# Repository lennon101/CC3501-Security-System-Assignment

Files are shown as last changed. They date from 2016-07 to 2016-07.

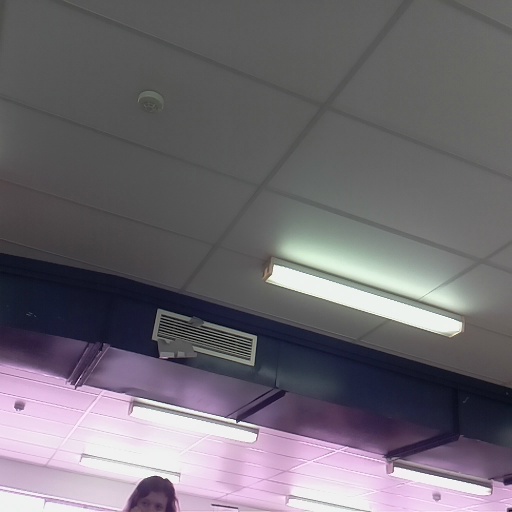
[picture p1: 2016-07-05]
SecuritySystem/src/images/1test.png

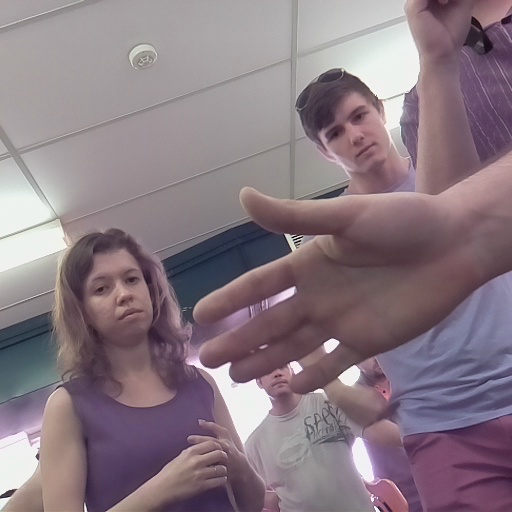
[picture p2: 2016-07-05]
SecuritySystem/src/images/5.png

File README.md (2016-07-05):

# CC3501-Security-System-Assignment

##ABSTRACT
The purpose of this project was to investigate, design and implement an indoor security system that involved wireless communication, motion detection, image processing as well as additional features including a website with a video stream and control features. The projects objective has been to innovate an easy to use and affordable system ready for consumer use. This technical report provides and overview of the investigation, design and implementation done to deploy the project prototype.

##CC3501
- GROUP 5: Dane Lennon, Michael Grasso, Stuart Hinchliff, Stephanie Baker

##Project Features and Functionality
This system involves the integration of both hardware and software. It features a custom microprocessor PCB with a PIR motion detecting sensor communicating with a Raspberry Pi via XBee communications.
The features of this project include:
- Webserver application interface with full functionality
- The ability to arm and disarm the system
- Low power initial motion detection using a PIR sensor
- A second check for motion detection with complex image detection algorithms
- Voice configuration mode 
- Ability to email and save screenshots

##Hardware Design
###Printed Circuit Board Design
When designing this system, it was a priority that it must be as small and efficient as possible and only include the minimum number of necessary hardware features on the PCB, these included:
- PIR sensor for motion detection,
- LED to indicate motion detection 
- USB 2.0 port for power and necessary power supply regulations 
- Xbee for Zigbee communication
- JTAG header for SEGA programming 
- Battery holder for backup power

To reduce the size of this board further, a custom microprocessor board was designed to replace the standard shield for a Freescale Board. The Freescale FRDM-K20D50M schematic was used as a reference through the design process. Therefore, the microprocessor design, including the clock source and decoupling capacitor designs, was executed similarly to a professional board design. Figure 3 shows the completed PCB. 

###Central Hub and Peripherals
Implementing a security system with advanced features such as image processing and voice control was a task that could only be performed using a highly functional and heavily customizable device. The obvious choice was a Raspberry Pi, with capabilities of a small computer running the Linux operating system. The Raspberry Pi offers all of the features required by the group to design the central hub. Additionally, many open-source libraries are available for Linux to assist with the necessary features of the system such as the development of image processing, voice control and video streaming.

The Raspberry Pi B+ model features two USB ports and a 3.5mm audio jack, allowing the group to attach all required devices with ease. Additionally, a ribbon camera designed specifically for the Raspberry Pi is available, allowed for easy connection of a camera. The list of peripherals used in this project are:
Raspberry Pi Camera Board 
- USB 2.0 Microphone 
- Wi-Pi USB 2.0 Connector
- Powered USB 2.0 Hub

##Software Design
Robust was fundamental to the project. The system integrates scripts in C, C++, Python, HTML, JavaScript, and many external frameworks and libraries. The two main scripts were the C++ code running the main hub, and the Python code operating the webserver. Details of the functionality are described below.

###Server and Web-application
In order to appropriately develop the project, the target audience and their needs were carefully considered. It was assumed that average users would have no prior technical experience with embedded systems, so the software was designed to be user friendly.
A number of control methods were contemplated in the design process, including the use of a Bluetooth or web application. Upon review of similar products available it was determined that a web application provided the flexibility desired with: 
- Range of use (only an internet connection required 
- Security (authentication methods)
- Interface (intuitive GUI)
- Accessibility on a range of devices
- Potential for expansion
 
Various frameworks were considered to host the server. Due to its popularity and power, the lightweight, Python-based, framework called Flask was chosen. Further, a Bootstrap template was used for the webpage structure to improve the visual appeal and enhance user experience.

####Video Streaming
Surveillance is becoming increasingly prevalent in security systems and was the main drive for developing a web application. The implementation of this was inspired by Miguel Grinberg’s live video stream [1], which demonstrated how versatile Flask could be.
The main complication with using Python was its compatibility with the existing C++ code. It was found that a conflict occurred when attempting to access the camera from Python (for video streaming) and C++ (for image processing) scripts simultaneously. To overcome this, it was decided that saving an image from the C++ code and loading it to Python was the most feasible option. This came with a variety of advantages and disadvantages. It reduced the complexity of the code and it also provided a saved image for use in other processes, but the continuous read/write of images does consume system time. Sockets were also considered, but for image matrices proved complicated and prone to problem.

####Web-Application Control
The website comprises of three main pages: dashboard, view screenshots, and email configuration. The functionality of the website is as follows: (see Figure 2 for flowchart):
- Dashboard: View the live stream and execute available commands.
- Arm (Default): Receive data from the PCB. If a 1 (motion detected) is received image processing code is executed and an email is sent to the saved address.
- Disarm: Stop receiving data from the PCB.
- Save a SnapShot: Capture image of the live stream.
- Email a SnapShot: Send an email of the current image to the saved address.
- Enable Voice: Turn on voice control, allowing the user to configure via voice. o Disable Voice (Default): Turn off voice control.

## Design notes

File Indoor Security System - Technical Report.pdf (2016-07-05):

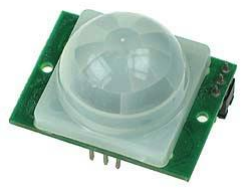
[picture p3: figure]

## Technical Report

### ABSTRACT

The purpose of this project was to investigate, design and implement an indoor security system that involved wireless communication, motion detection, image processing as well as additional features including a website with a video stream and control features. The projects objective has been to innovate an easy to use and affordable system ready for consumer use. This technical report provides and overview of the investigation, design and implementation done to deploy the project prototype.

GROUP 5: Dane Lennon, Michael Grasso,

### Stuart Hinchliff, Stephanie Baker

CC3501

## Contents

# 1. Project Overview

### 1.1 Project Approach

The investigative approach of the Indoor Security System Project began with researching systems currently on the market and analysing their specifications. It was found that most existing systems integrate motion detection algorithms with a continuously running camera to detect motion. One of the design criteria of this project was to utilise a low-power sensor network to implement motion detection over a large area with minimal cost. Therefore, using the camera continuously for motion detection was not suitable.

To minimize the use of the camera, a Photoelectric (“Passive”) Infrared Sensor was implemented. It was chosen for several reasons, including its ability to detect changes in infrared radiation as well as its low cost and low power consumption. If there is a differential change within the scope of the sensor, the sensors convert it into an output voltage, which represents a detection, illustrated in Figure 1.

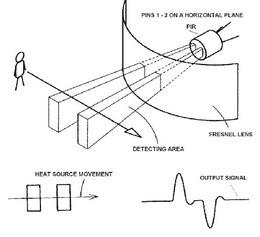
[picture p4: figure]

### 1.2 Project Features and Functionality

This system involves the integration of both hardware and software. It features a custom microprocessor PCB with a PIR motion detecting sensor communicating with a Raspberry Pi via XBee communications.

The features of this project include:
- Webserver application interface with full functionality
- The ability to arm and disarm the system
- Low power initial motion detection using a PIR sensor
- A second check for motion detection with complex image detection algorithms
- Voice configuration mode
- Ability to email and save screenshots

Included in Figure 2 is a flow chart illustrating how the system works when being controlled by the user.

Figure 1: PIR SENSOR [2]

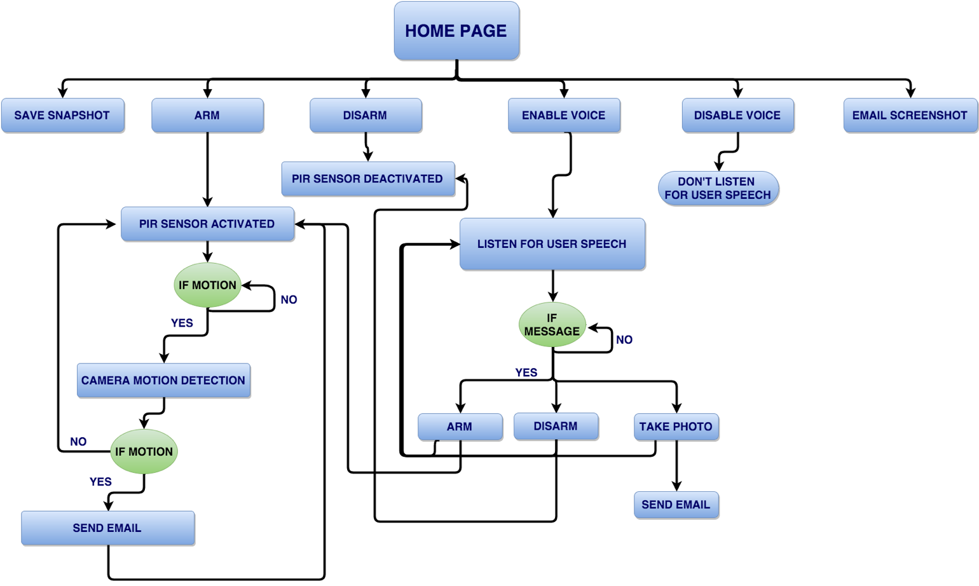
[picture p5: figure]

## 2. Hardware Design

### 2.1 Printed Circuit Board Design

When designing this system, it was a priority that it must be as small and efficient as possible and only include the minimum number of necessary hardware features on the PCB, these included:

- PIR sensor for motion detection,
- LED to indicate motion detection
- USB 2.0 port for power and necessary power supply regulations
- Xbee for Zigbee communication
- JTAG header for SEGA programming
- Battery holder for backup power

To reduce the size of this board further, a custom microprocessor board was designed to replace the standard shield for a Freescale Board. The Freescale FRDM-K20D50M schematic was used as a reference through the design process. Therefore, the microprocessor design, including the clock source and decoupling capacitor designs, was executed similarly to a professional board design. Figure 3 shows the completed PCB.

Figure 2: Flow Chart- System Design

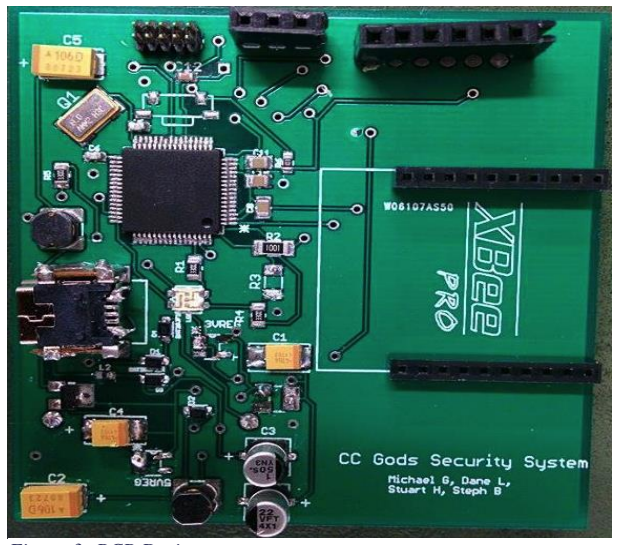
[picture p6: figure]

### 2.2 Communications Network

The wireless communications network utilised in this system is a ZigBee mesh network. The ZigBee network used consists of one Coordinator connected to the Raspberry Pi and one Router connected to PCB. This was designed so multiple PCBs can be distributed, automatically forming a mesh network with the Coordinator at the central hub. Figure 4 illustrates the ZigBee communication network outlined above.

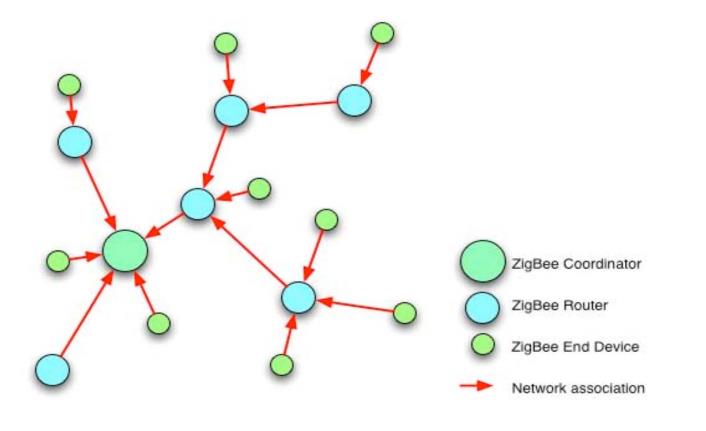
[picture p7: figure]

### 2.3 Central Hub and Peripherals

Implementing a security system with advanced features such as image processing and voice control was a task that could only be performed using a highly functional and heavily customizable device. The obvious choice was a Raspberry Pi, with capabilities of a small computer running the Linux operating system. The Raspberry Pi offers all of the features required by the group to design the central hub. Additionally, many open-source libraries are available for Linux to assist with the necessary features of the system such as the development of image processing, voice control and video streaming.

The Raspberry Pi B+ model features two USB ports and a 3.5mm audio jack, allowing the group to attach all required devices with ease. Additionally, a ribbon camera designed specifically for the Raspberry Pi is available, allowed for easy connection of a camera. The list of peripherals used in this project are:

- Raspberry Pi Camera Board

Figure 3: PCB Design

Figure 4: ZigBee Network [5]

- USB 2.0 Microphone
- Wi-Pi USB 2.0 Connector
- Powered USB 2.0 Hub

These peripherals were connected to the powered USB 2.0 hub to ensure devices would receive enough power and not switch off.

## 3.0 Software Design

Robust was fundamental to the project. The system integrates scripts in C, C++, Python, HTML, JavaScript, and many external frameworks and libraries. The two main scripts were the C++ code running the main hub, and the Python code operating the webserver. Details of the functionality are described below.

### 3.1 Main Loop

The main loop controls the system and is responsible for automation of the security system. The structure of the code is demonstrated Figure 5.

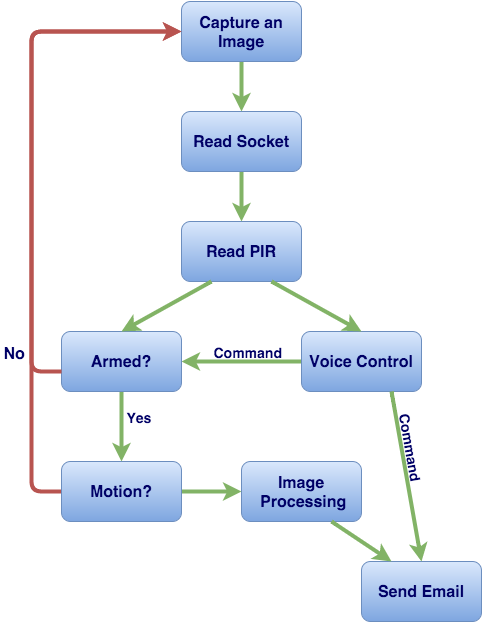
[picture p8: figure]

### 3.2 Server and Web-application

In order to appropriately develop the project, the target audience and their needs were carefully considered. It was assumed that average users would have no prior technical experience with embedded systems, so the software was designed to be user friendly.

A number of control methods were contemplated in the design process, including the use of a Bluetooth or web application. Upon review of similar products available it was determined that a web application provided the flexibility desired with:

- Range of use (only an internet connection required)
- Security (authentication methods)
- Interface (intuitive GUI)
- Accessibility on a range of devices
- Potential for expansion

Figure 5: Main Loop Logic

Various frameworks were considered to host the server. Due to its popularity and power, the lightweight, Python-based, framework called Flask was chosen. Further, a Bootstrap template was used for the webpage structure to improve the visual appeal and enhance user experience.

3.2.1. Video Streaming
Surveillance is becoming increasingly prevalent in security systems and was the main drive for developing a web application. The implementation of this was inspired by Miguel Grinberg’s live video stream [1], which demonstrated how versatile Flask could be.

The main complication with using Python was its compatibility with the existing C++ code. It was found that a conflict occurred when attempting to access the camera from Python (for video streaming) and C++ (for image processing) scripts simultaneously. To overcome this, it was decided that saving an image from the C++ code and loading it to Python was the most feasible option. This came with a variety of advantages and disadvantages. It reduced the complexity of the code and it also provided a saved image for use in other processes, but the continuous read/write of images does consume system time. Sockets were also considered, but for image matrices proved complicated and prone to problem.

3.2.2 Web-Application Control
The website comprises of three main pages: dashboard, view screenshots, and email configuration. The functionality of the website is as follows: (see Figure 2 for flowchart):
- Dashboard: View the live stream and execute available commands.
- Arm (Default): Receive data from the PCB. If a 1 (motion detected) is received image processing code is executed and an email is sent to the saved address.
- Disarm: Stop receiving data from the PCB.
- Save a SnapShot: Capture image of the live stream.
- Email a SnapShot: Send an email of the current image to the saved address.
- Enable Voice: Turn on voice control, allowing the user to configure via voice.
- Disable Voice (Default): Turn off voice control.

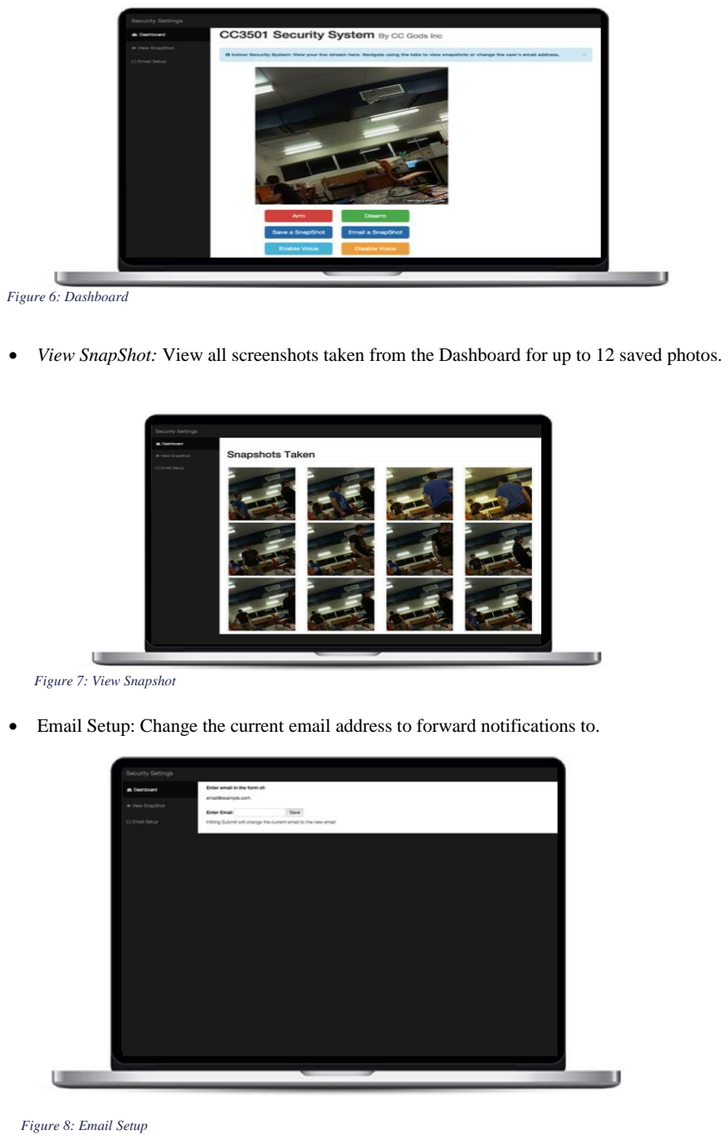
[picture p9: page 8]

- View SnapShot: View all screenshots taken from the Dashboard for up to 12 saved photos.
- Email Setup: Change the current email address to forward notifications to.

Figure 6: Dashboard

Figure 7: View Snapshot

Figure 8: Email Setup

3.2.3 Integration
Multilingual programming was an important aspect of the overall project. In order to ensure various scripts cooperated together, careful consideration of individual tasks and the overall product was taken in design.

The ability to email from the application was a significant feature, with details on its implementation available in Section 3.5. The Python script containing the code is called using a system call from either the C++ or Python code. Due to the sequential nature of the languages used, this caused a halt in the program preventing streaming, voice control and most importantly motion detection. To overcome this, forks were implemented.

Forks are a system call used in Unix-based systems in which a process creates a copy of itself. This process is best explained through the use of a flowchart:

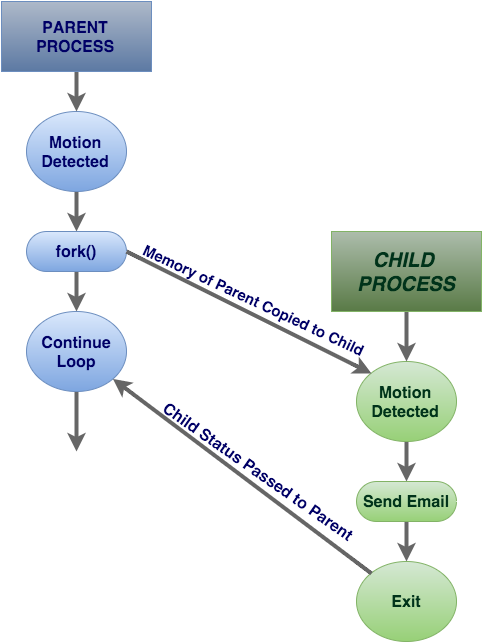
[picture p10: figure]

The C++ script creates a fork when motion is detected, prior to calling the email function. The parent continues looking for motion while the child process simultaneously executes the email script and is then destroyed.

Acquiring information from the website and sharing it between processes was a crucial part of controlling the system. Flask handled routes from the HTML script, so button clicks were accessible from Python. Non-blocking UDP/IP sockets were then used to transfer the information to the C++ code. UDP/IP was chosen as only two Boolean numbers needed to be sent, and the lack of error checking and overhead increased speed. Additionally, as the sockets were operating on the same system, there would be no loss of data and no need for retransmission.

### 3.3 Voice Control

The concept of voice control is a very marketable design and could potentially be implemented a variety of ways into any system in order to create an easy-to-use interface for the consumer. It was introduced to this security system as a prototype level feature. In future, it could be expanded to have more complete control.

Figure 9: Flow Chart- Fork

3.3.1 Speech-To-Text Input

There are several speech-to-text engines available for the Raspberry Pi. The two engines considered were Pocketsphinx and Julius, both well known for their voice recognition capabilities. After research on these two speech engines it was determined that Pocketsphinx was the engine best suited to a project with small sentence structures. It is designed for small systems and implements natural language processing, including advanced algorithms such as n-grams and Hidden Markov Models. A logic diagram for Pocketsphinx can be seen in Figure 10.

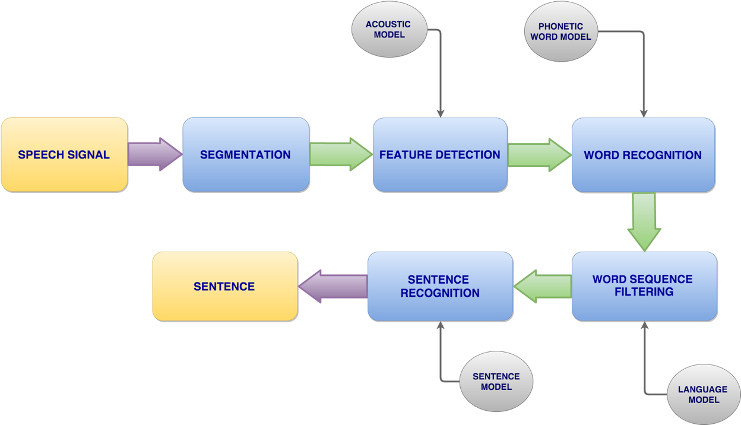
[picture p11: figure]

This speech engine required extensive configuration and modification to suit our purposes. Word recognition was improved using a grammar model tool by Carnegie Mellon University, which involved creating a .txt file containing required commands. The tool generated language and dictation models which were implemented in the C++ code. The dictation model file was then manually modified to include pronunciations consistent with the Australian accent, as initially it contained only American pronunciations.

3.3.2. Text-to-Speech Output
In order to complete a full speech structure, speech synthesis allows the system to talk back to the user. After researching several speech synthesis engines, eSpeak was implemented due to its usability. It was implemented in the C++ code through a system call to pass a string to command line which would generate the desired speech response. Text-to-speech output was used to interact with the user while voice control configuration was active.

### 3.4. Image Processing for Motion Detection

3.4.1. Image Processing Techniques
There are a number of ways to approach detecting motion using a camera. After extensive research the method which was utilised in this algorithm was the comparison of three frames captured after slight time delay in order optimise the reduction of would background noise. The images are stored as 512 x 512 pixel matrices and processed in C++ with the implementation of OpenCV libraries. The absdiff() function was used twice to take the element-by-element absolute difference between two matrices and return a resultant matrix. Example output of absdiff() is seen in Figure 11.

Figure 10: Flow Chart- Pocketsphinx

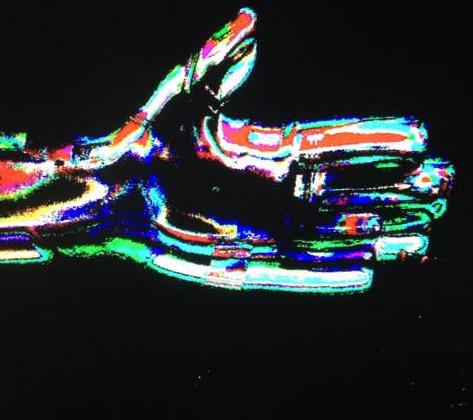
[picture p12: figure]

Figure 11 - Image of moving hand after absdiff() is applied

Figure 11 shows that there are some undesired image artefacts, such as the cluster of white pixels in the bottom right corner. In the application of motion detection, it is undesirable to have this background noise in difference images as it triggers a false positive for movement.

To remove artifacts in images, the frames were compared using an OpenCV function bitwise_and(), which takes two image matrices as input and performs a logical ‘and’ operation on each pixel, resulting in a significant reduction of background artifacts. Thisfunction produces a resultant matrix where pixels which are the same colour in image 1and image 2 are returned unchanged, while all other pixels are converted to black.

After artefact removal, the image is converted to greyscale and binary thresholding is performed to eliminate remaining background noise while preserving the foreground image. Binary thresholding returned an image whereby white pixels represent pixels that changed colour between frames, while black pixels are those that remained the same colour.

It was determined through manual testing that if the white pixel count was over 20 pixels, motion had occurred. A bounding rectangle was drawn around the movement region by generating a rectangle between minimum and maximum (x, y) coordinates of the detected movement and overlaying it on captured frames. This makes it easier to pinpoint the source of movement.

### 3.5 Emailing System

The security system has been implemented with an emailing system with two methods of activation. Emailing of images can be triggered manually from the webpage, or automatically by the C++ code if motion is detected.

3.5.1 Manually Capture and Email a Snapshot
The email system was written in Python, using StackOverflow as a guide. The script is run from the command line and contains information about the location of the images to attach and the addresses of sender and receiver. The website dashboard includes a button to manually email a snapshot. The onClick listener of the button calls a function attached to an xhttp route which executes the Python script on the server side.

3.5.2 Automatic Email Alert
When motion is detected by the C++ code, a fork is created and the child process sends an email via a system call to the Python Script.

## 4.0 Limitations and Recommendations

### 4.1 Hardware

4.1.1 Component Limitations
The design of the Printed Circuit Board (PCB) was derived from the Freescale Freedom schematic and similar components chosen to match the design. However, during implementation, some components intermittently failed. This included an unresolved voltage output error from the buck boost regulator, which returned approximately 3.7V instead of the expected 5V. The system was redesigned using a though-hole 3.3V linear regulator to overcome this, but the required component could not be purchased before project completion due to time constraints. Further, the use of the linear regulator would have resolved the first issue but in turn produced a second issue where the battery could not have been used.

4.1.2 Design Flaws
During the design stage, flaws occurred in the PCB schematic layout when the USB footprint was placed backwards on the Eagle board layout.

This design flaw was overcome by soldering the USB facedown and wiring the pins of the USB to the tracks of the PCB as shown below. A copper sheet was used to ensure the USB did not make any undesired electrical connections with other PCB tracks. This worked well as a fix, but in the future the design could be easily corrected.

Lastly, the design made use of a surface mounted microprocessor. After the components were placed on the board, it became evident that too much solder paste had been used around the terminals of the processor, as shown below. This resulted in time-consuming re-soldering before the PCB was at a satisfactory level.

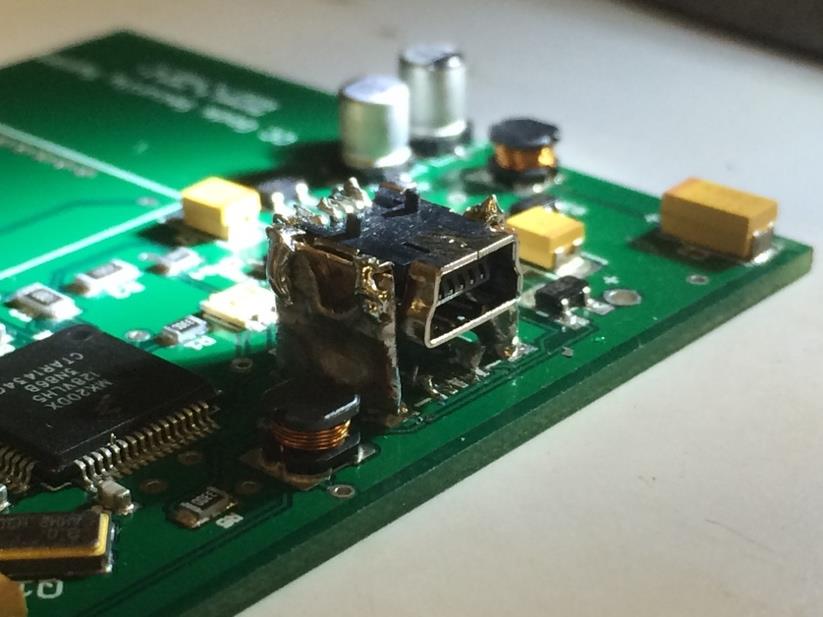
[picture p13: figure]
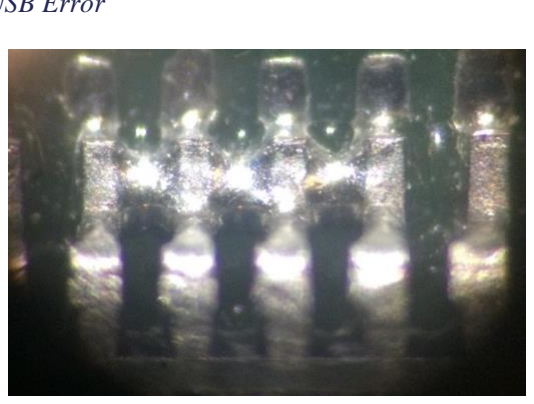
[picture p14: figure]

Figure 12: USB Error

4.1.3 Future Design Implementations
The initial scope of the project included a custom made 3D printed case to house the PCB. However, due to the time constraints of the project the implementation of this feature was discarded in order to prioritized the technical design. Future designs would also resolve the issues outlined above, and off-the-shelf installation and implementation would be implemented for increased usability.

### 4.2 Software

4.2.1 Voice Control
The implementation of voice control was limited by the recognition engine and microphone quality. Background noise needed to be removed for full accuracy, and the engine did not process all voices with equal effectiveness. While this is a software limitation, it could be overcome by improving the engine to accept a wider variety of voice pitches, dialects and accents. However, this was outside the reasonable scope of a time-constrained project. Voice control also needed to be listening at all times to recognize words, which became problematic when the C++ code also needed to listen to a socket and the XBee.

4.2.3 Saving images
Currently, the system has been designed to save the images to the Pi and load the images to the webpage. This is not an ideal implementation and could be improved using sockets. This would involve sending the data from the C++ code to the Python code in matrix format via UDP/IP. The client side (Python) would receive the matrix and format the image for webpage display.

4.2.4 Image Detection
The image detection algorithm was optimized for an indoor environment, where movement is minimal and lighting is consistent. For an outdoor environment with a dynamic background, new algorithms would need to be developed to accurately detect only relevant movement.

## 5.0 Conclusion

The scope of the project included the design and implementation of a security system that made use of wireless communication between microcontrollers, motion detection and multiple methods of control such a web app and voice control. These design requirements were successfully implemented with only a few limitations. While most limitations were due to uncontrollable parameters, some flaws were introduced that could have been avoided and these have been documented for future designs. The final product provides a suitable working prototype of an affordable system that implements complex security measures.

Figure 13: Solder Paste Error

## 6.0 References

[1]M. Grinberg, 'Video Streaming with Flask - miguelgrinberg.com', Blog.miguelgrinberg.com, 2014. [Online]. Available: http://blog.miguelgrinberg.com/post/video-streaming-with-flask. [Accessed: 27-Oct- 2015].

[2] Learn.adafruit.com, 'How PIRs Work | PIR Motion Sensor | Adafruit Learning System', 2015.
[Online]. Available: https://learn.adafruit.com/pir-passive-infrared-proximity-motion-sensor/how-pirs-work. [Accessed: 27- Oct- 2015].
[3] Speech.cs.cmu.edu, 'The CMU SLM Toolkit', 2015. [Online]. Available: http://www.speech.cs.cmu.edu/SLM_info.html. [Accessed: 27- Oct- 2015].
[4] Flask.pocoo.org, 'Welcome | Flask (A Python Microframework)', 2015. [Online]. Available:
http://flask.pocoo.org/. [Accessed: 27- Oct- 2015].
[5] Lecture Notes; Bronson Philippa-CC3501

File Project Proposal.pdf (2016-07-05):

## Project Proposal: Security System

Our proposed project will implement a variety of sensors to create an example of a sophisticated security system. The system will use motion detection to trigger a camera which will capture images of the perpetrator. These images will then be emailed to the user. The system will involve a Raspberry Pi and a Freedom Board with a manufactured shield, which will communicate with each other wirelessly using XBees.

### The Freedom Board & Shield

We will design a shield featuring a PIR sensor, LED lights to show armed/disarmed status, and a buzzer to act as an alarm. Additionally, we will include extra ports for analogue voltage measurements to ensure that more sensors could be added to the system as required.

### The Raspberry Pi

Our Raspberry Pi will be our central hub. It will have an XBee attached to give it the ability to receive data from the Freedom Board. It will have a camera connected to it which will capture photos of the desired area as required. It will also be connected to the internet so that captured photos and relevant sensor data for a security breach can be emailed to the user’s email address.
There will also be an audio sensor attached. It will analyse the user’s vocal spectrum as well as listening for a pre-set password. If both the vocal spectrum and password match, the system will unlock and the user will be able to:
- Arm/disarm the entire system
- Enable/disable the alarm, without disabling email alerts.
- Enable/disable the camera, even if no motion is detected.

### The Interface

A secure password-protected interface will also be available to the user. This interface will have the following features:

- Display of sensor readings.
- Enable/disable individual sensors.
- Ability to arm/disarm the entire system.
- Enable/disable the alarm, without disabling email alerts.
- Enable/disable the camera, with the option to view live feed from the camera.

### The Communications

The Freedom Board will transmit data to the Raspberry Pi using XBees at regular intervals. The Freedom Board will set off the alarm if any of its included sensors detect motion. The Raspberry Pi will also transmit back to the Freedom Board; the alarm will need to be turned off by the user via the interface or audio sensors attached to the Raspberry Pi. The Raspberry Pi will also be able to transmit information to the user via email. The Raspberry Pi will take input from the user to enable/disable features through the interface or audio sensor, as described above.

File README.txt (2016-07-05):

To run the code, do it the way we do in labs: 
> $ cd SecuritySystem/build
> $ ./main

The main.cpp file - photo capture:
> There is one function that takes one photo as input and simply saves it
> This is the photo we will use for our stream
> It doesn't matter how often you upload the photo because there will always be an
  image with the right name there
> But the main loop is capturing an image every 10 loops
> The image is called "streamImage.jpg" and is found in the src directory

The main.cpp file - motion detection:
> There is one function that takes three frames and compares them for motion
> The difference between frame 1 and 3 is taken (3 being most recent capture)
> The difference between frame 2 and 3 is taken
> An "and" operation is performed on the differences so that only pixels that
  were changed in difference 1 AND difference 2 are counted (this eliminates
  a LOT of background noise)
> Then the image is converted to greyscale and thresholded 
> Thresholding could be upped from 25 to 30, but I found best accuracy with 25
  in my bedroom
> A very small amount of background noise may occur when a fan is on (I found that
  the clothes on my clothes line were moving just enough to trigger about 2-8 pixels
  of "difference") so the pixel count for "motion" has been set so that more than
  10 pixels of movement will signify motion. Might have to finetune this for the 
  robo club room.
> It picks up even small motion up to ~3m away, pls appreciate how stupid I felt jumping
  up and down on my bed and yelling "TAKE PHOTO" at my Pi to test this.
> It should pick up motion further away, still need to run those tests.
> If motion is detected, the images are saved. And this is where we need to add the email
  functionality.

The main.cpp file - voice recognition
> There are 5 commands as it stands, but I'm happy to add more.
> "HELLO" - puts the voice control system into configuration mode, the system WILL NOT LISTEN
  for any other commands until you say "HELLO" to wake it up.
> "ARM" - arms the system, we still need to talk about what we're going to classify as "arming
  the system".
> "DISARM" - disarms the system
> "TAKE PHOTO" - tests the motion detection. Ask the program to take a photo and it will capture
  three frames, and it will verbally tell you whether it detected motion or not. GREAT way to
  check that motion detection is working as it should, and it will let us know if we need to
  fine tune for background noise in a bigger room. Probably my favourite voice control feature.
> "GOODBYE" - puts the voice control back into "not listening" mode. He won't listen for anything
  except the word "HELLO", so the loop will run full speed and the stream will be updated constantly.
> If we want to change these PLEASE PLEASE PLEASE let me do it, I've spent a lot of time
  working on the algorithms behind language models and dictation and I have a pretty deep
  understanding of what's going to work best -- and on that note I've tested a lot of words for the
  above functions and these are the ones I've had the most success and highest accuracy rate with.
> If any of you find that voice control isn't understanding you when you say one of the 
  commands, send me a voice clip of you saying the command and I'll add your pronunciation of the
  command to our dictation model.

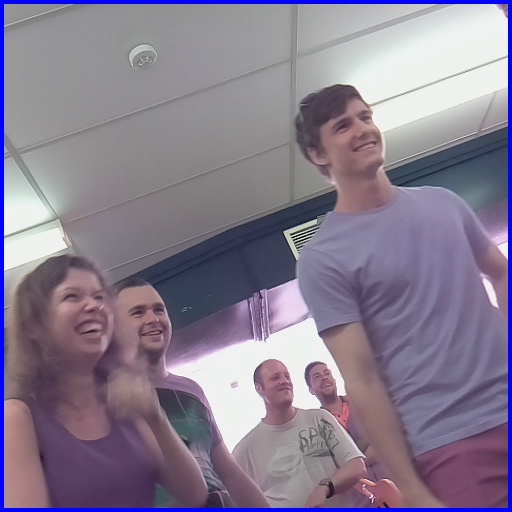
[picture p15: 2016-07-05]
SecuritySystem/src/frame2.jpg

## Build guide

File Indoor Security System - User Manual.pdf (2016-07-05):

## Group 5 CC3501

### Stuart Hinchliff, Michael Grasso, Dane Lennon, Stephanie Baker

# INDOOR SECURITY SYSTEM

## User Manual

### Indoor Security System

## Contents

## 1. Security System Contents

### 1.1. Main Hub

The main hub of the security system contains the following items:
- 1 x Raspberry Pi Model B
- 1 x Raspberry Pi Camera Module + Stand
- 1 x WiPi Dongle
- 1 x USB Microphone
- 1 x Speakers with 3.5mm Audio Jack Connectivity
- 1 x Power Adapter
- 1 x XBee Pro

### 1.2. Wireless Motion Detector Module

The lightweight motion sensing module kit contains the following items:
- 1 x Sensor Board
- 1 x XBee Pro
- 1 x Coin Cell Battery
- 1 x Power Adapter

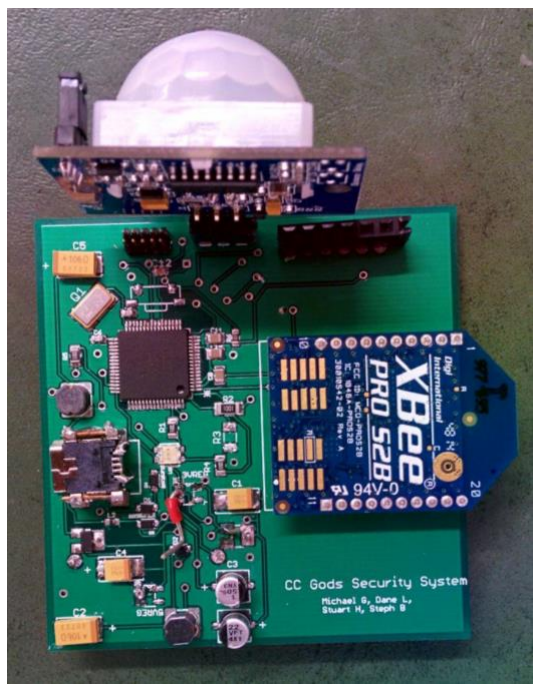
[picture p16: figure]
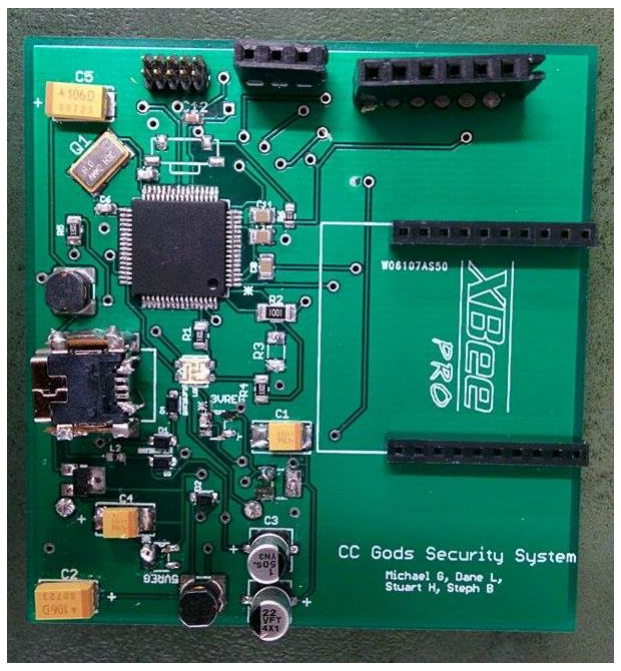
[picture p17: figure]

Figure 1: Sensor board with peripherals | Figure 2: Sensor board

## 2. Physical Installation

### 2.1. Main Hub

The following steps outline how to set up your main hub:
1. Remove camera from anti-static bag and connect it to the camera slot. The camera slot is located behind the Ethernet port. Lift the corners of the camera slot up carefully, until it unclicks. Slide the camera ribbon into the camera slot with the small metal contacts facing away from the Ethernet port. Gently lock the camera slot back into place by pressing the corners until it clicks.
2. Stabilize the camera by affixing it to a wall or other unmoving surface.
3. Connect the WiPi dongle to one of the available USB slots and configure it to your home network as per the instructions provided with the WiPi.
4. Connect the USB microphone to the remaining available USB slot.
5. Connect the speakers to the blue 3.5mm audio jack.
6. Connect the XBee via USB
7. Connect the mini USB end of the power adapter to the board, and then plug it into a power socket and turn on.
8. The program will run on power up.

### 2.2. Wireless Motion Detector Module

The following steps outline how to set up your wireless motion detector module:
1. Connect the XBee, aligning it with the image printed on the board.
2. Insert one coin cell battery.
3. Affix the board to any surface, ensuring the large sensor faces outwards so that it is able to detect motion.
4. Connect the mini USB end of the power adapter to the board, and then plug it into a power socket and turn on.

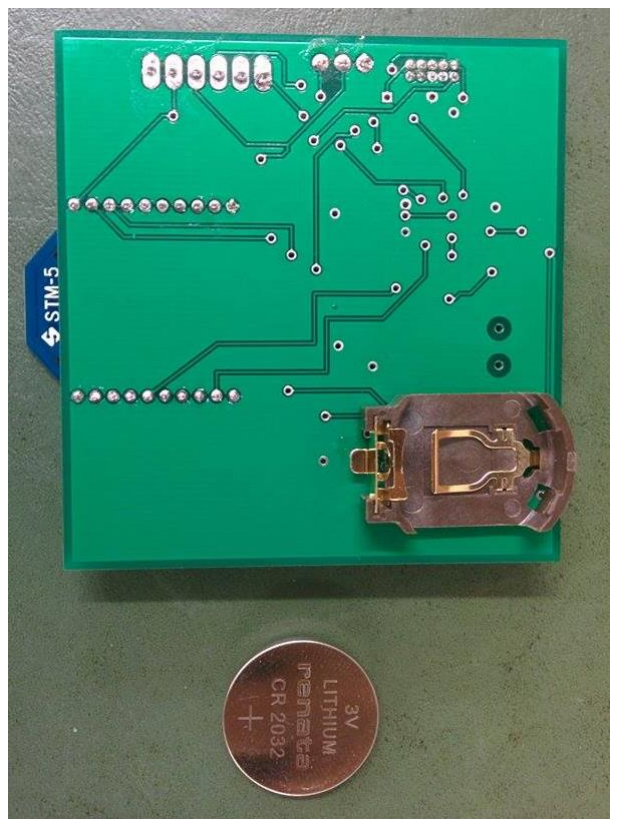
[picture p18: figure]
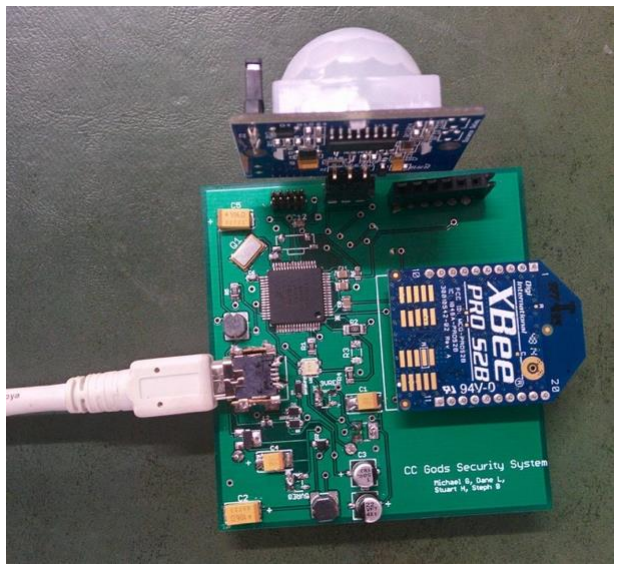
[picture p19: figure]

Figure 3: Powered by USB | Figure 4: Powered by coin cell

## 3. Web-application

This security system hosts a webserver for the user to control the settings and view a live stream from the camera. The website is accessible from any web browser on devices including computers, tablets and phones by simply typing the IP address “192.168.35.196:5000” into the address bar.

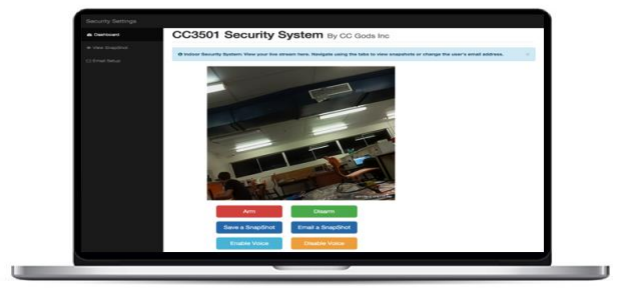
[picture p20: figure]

Figure 5 - Webserver homepage

If the website is working as it should be, you should be presented with the homepage seen in Figure 5. There will be an active video stream with 6 buttons offering the following features:

- “Arm” – puts the system into “watching” mode, where it is actively watching for motion and will send you email alerts should motion be detected. The stream remains accessible at all times.
- “Disarm” – puts the system into “sleep” mode, where it does not look for motion. The stream will still be accessible at all times.
- “Save Snapshot” – captures and saves a snapshot of the video stream. Snapshots can be viewed by navigating to the “View Snapshots” tab.
- “Email Snapshot” – captures an image and emails it to the email address specified by the user.
- “Enable Voice” – turns on voice control configuration mode. Use voice control as per the instructions in section 4.
- “Disable Voice” – turns of voice control configuration mode.

From the homepage there are also two other pages accessible from the navigation bar on the left. These are:

- View Snapshots – this page will display the 16 most recent snapshots captured by the “Save Snapshot” function on the dashboard.
- Email Setup – this page allows the user to configure which email address they would like images to be emailed to them at by the system. Simply enter your email and press ‘save’.

## 4. Voice Control

This indoor security system implements voice control to make configuration of the system hands-free:

- “ARM” – puts the system into “watching” mode, where it is actively watching for motion and will send you email alerts should motion be detected. The stream remains accessible at all times.
- “DISARM” – puts the system into “sleep” mode, where it does not look for motion. The stream will still be accessible and voice commands can still be used.

- “TAKE PHOTO” – allows you to test motion detection. Saying “TAKE PHOTO” will prompt the system to take three photos and check them for motion.
- If motion is detected, the system will verbally inform you that motion occurred as well as emailing you images of the motion.
- If motion is not detected, the system will inform you that the coast is clear.
- NB: it is recommended that you test motion detection by using the “TAKE PHOTO” command on a still room, and using it again whilst you or another person moves in front of the camera.
- “GOODBYE” – exits configuration mode. Commands will not be accessible until voice control is turned on again via web application.

## 5. Troubleshooting

The program isn’t running when I turn on my Raspberry Pi.
The software on the Raspberry Pi will not run unless both the camera and the USB microphone are connected correctly. Please ensure that the camera is connected gently but firmly into the camera slot, and that the USB microphone has been correctly inserted into a USB slot.

The camera isn’t detecting motion correctly.
The motion detection software has been optimized for indoor usage only. Please ensure that the camera is facing a still background and is securely fastened on a stable surface. Additionally, ensure that the camera is in a well-lit room.

Voice control isn’t hearing me well.
Voice control works best when there is no background noise so it can focus on what you’re saying. It has been optimized for both American and Australian accents, and may struggle with variations from these. Try to speak clearly, in a quiet room, and repeat commands if prompted.

Voice command isn’t executing my commands and isn’t responding.
Ensure that you have said “HELLO” and voice control has responded to you. If this has not occurred, then voice control is not in configuration mode. Say “HELLO” to enter configuration mode. Voice control will greet you and inform you that it is in configuration mode.

The video stream appears frozen.
Ensure that voice control is not in configuration mode. If voice control is in configuration mode, the stream will not update regularly. If voice control is not in configuration mode, check your internet connection.

Motion is not being automatically detected by the wireless sensor module.
Communications between your wireless sensor module and your main hub may have been disrupted. Please check that XBees are firmly connected to their respective boards. Also ensure that the PIR sensor has a clear view of the room.

The website isn’t loading.
Check that your home network is working correctly, and ensure that the WiPi has been configured correctly for your home network. If needed, restart the Raspberry Pi.

I’m not receiving emails.
Ensure that you have configured the system to send to your email address via the website, referring to instructions in Section 3. Also ensure that your home network is working correctly, and that the WiPi has been configured for your home network.

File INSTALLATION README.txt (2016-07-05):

~~ BOYS PLS READ THIS ~~

Yay, voice control. I think the easiest option is just to not touch anything on my Pi ever again and
run the program from it, but if you want to give installing it on your Pi's follow these instructions:

~ PASSO UNO ~
- aka Step 1
- Just to be safe, update your Pi by typing the following commands:
	apt-get update
	apt-get upgrade
- pls note that you need Internet on your Pi for apt-get to work
	- There is a super handy trick you can use to get URLs for the packages you need, if you don't have an
  	  Internet connection on your Pi, type this into command:
		apt-get -y install --print-uris package_name

	  where package_name will be replaced with, well, the package name that you're looking for.
	- this handy tip will give you the URLs for downloading the packages and their dependencies! Yay!
	- then you download them, put them somewhere useful, navigate to the directory they're in and type in
  	  the following command:
		sudo dpkg -i *.deb
	- woohoo software! This comes in handy again later.

~ PASSO DUE ~
- Okay, now the instructions I followed told me to do more updates but yeah nah.
- Now we plug in our USB Mic, which in retrospect may be the hardest step seeing I have it.
- Type the following command:
	nano /etc/modprobe.d/alsa-base.conf
- Nano is a neat text editor in command line, so that's nice.
- Just be careful not to type anything in the wrong spot.
- Find where it says "options snd-usb-audio index=-2"
- Change that -2 to a 0
- Save & exit following the nano instructions that are on your screen.

~ PASSO TRE ~
- It's a good idea to force a reload of the alsa-base.conf file and the Pi itself
- In command type:
	alsa force-reload
	sudo reboot
- You'll have to log in again but everything should be there

~ PASSO QUATTRO ~
- Check that the last few steps worked by typing:
	cat /proc/asound/cards
- You should now see the USB Mic as the number '0' device. If this is the case, yay, good job!
- You can test further by doing this:
	arecord -d 5 -r 48000 test.wav
- IT HAS TO BE A .wav FILE
- This will record a 5 second sound clip in the current directory which you can listen to and check that your audio input is A-OK

~ PASSO CINQUE ~
- Now we need to install things.
- Please go to the software folder, I've already got it all there for you.
- Type the following command:
	sudo dpkg -i *.deb
- This should install all the Debian files that are needed to run Pocketsphinx
- What they do? No clue. Things I assume. I just know that we need them installed before we install Pocketsphinx & Sphinxbase
- And now that I've added the text-to-speech thing, there's some more software to install.
- Navigate to the espeak_software folder and type the same command:
	sudo dpkg -i *.deb
- That should be all you need to do for eSpeak

~ PASSO SEI ~
- Pocketsphinx is dependent on Sphinxbase, so we need to install it first
- Navigate into the 'sphinxbase-5prealpha' folder
- Again, I've done all the fiddly stuff, so you should just be able to type:
	./configure --enable-fixed
- And when that's done:
	make
- Wait a while longer, then to finish it off:
	sudo make install
- Go make a tea, that one takes a while.

~ PASSO SETTE ~
- Pretty much the same as the last step
- Navigate into the 'pocketsphinx-5prealpha' folder
- Type the following commands, in order:
 	./configure
	make
	sudo make install
- And now make another tea. Seriously, it takes a while.
- And to wrap it all up, type:
	LD_LIBRARY_PATH=/usr/local/lib

~ PASSO OTTO ~
- Okay, now to test things!
- To make it simple, do this:
	cd
	cd pocketsphinx/pocketsphinx-5prealpha/src/programs
	pocketsphinx_continuous -dict 9173.dic
- What should happen now is....
	- things will show your current configurations, which aren't really important
	- it will say READY... and listen
	- say "SETTINGS" to see the possible commands :)
	- probs have a clean pair of pants nearby cause this is exciting stuff and you may need 'em

THAT'S ALL FOLKS

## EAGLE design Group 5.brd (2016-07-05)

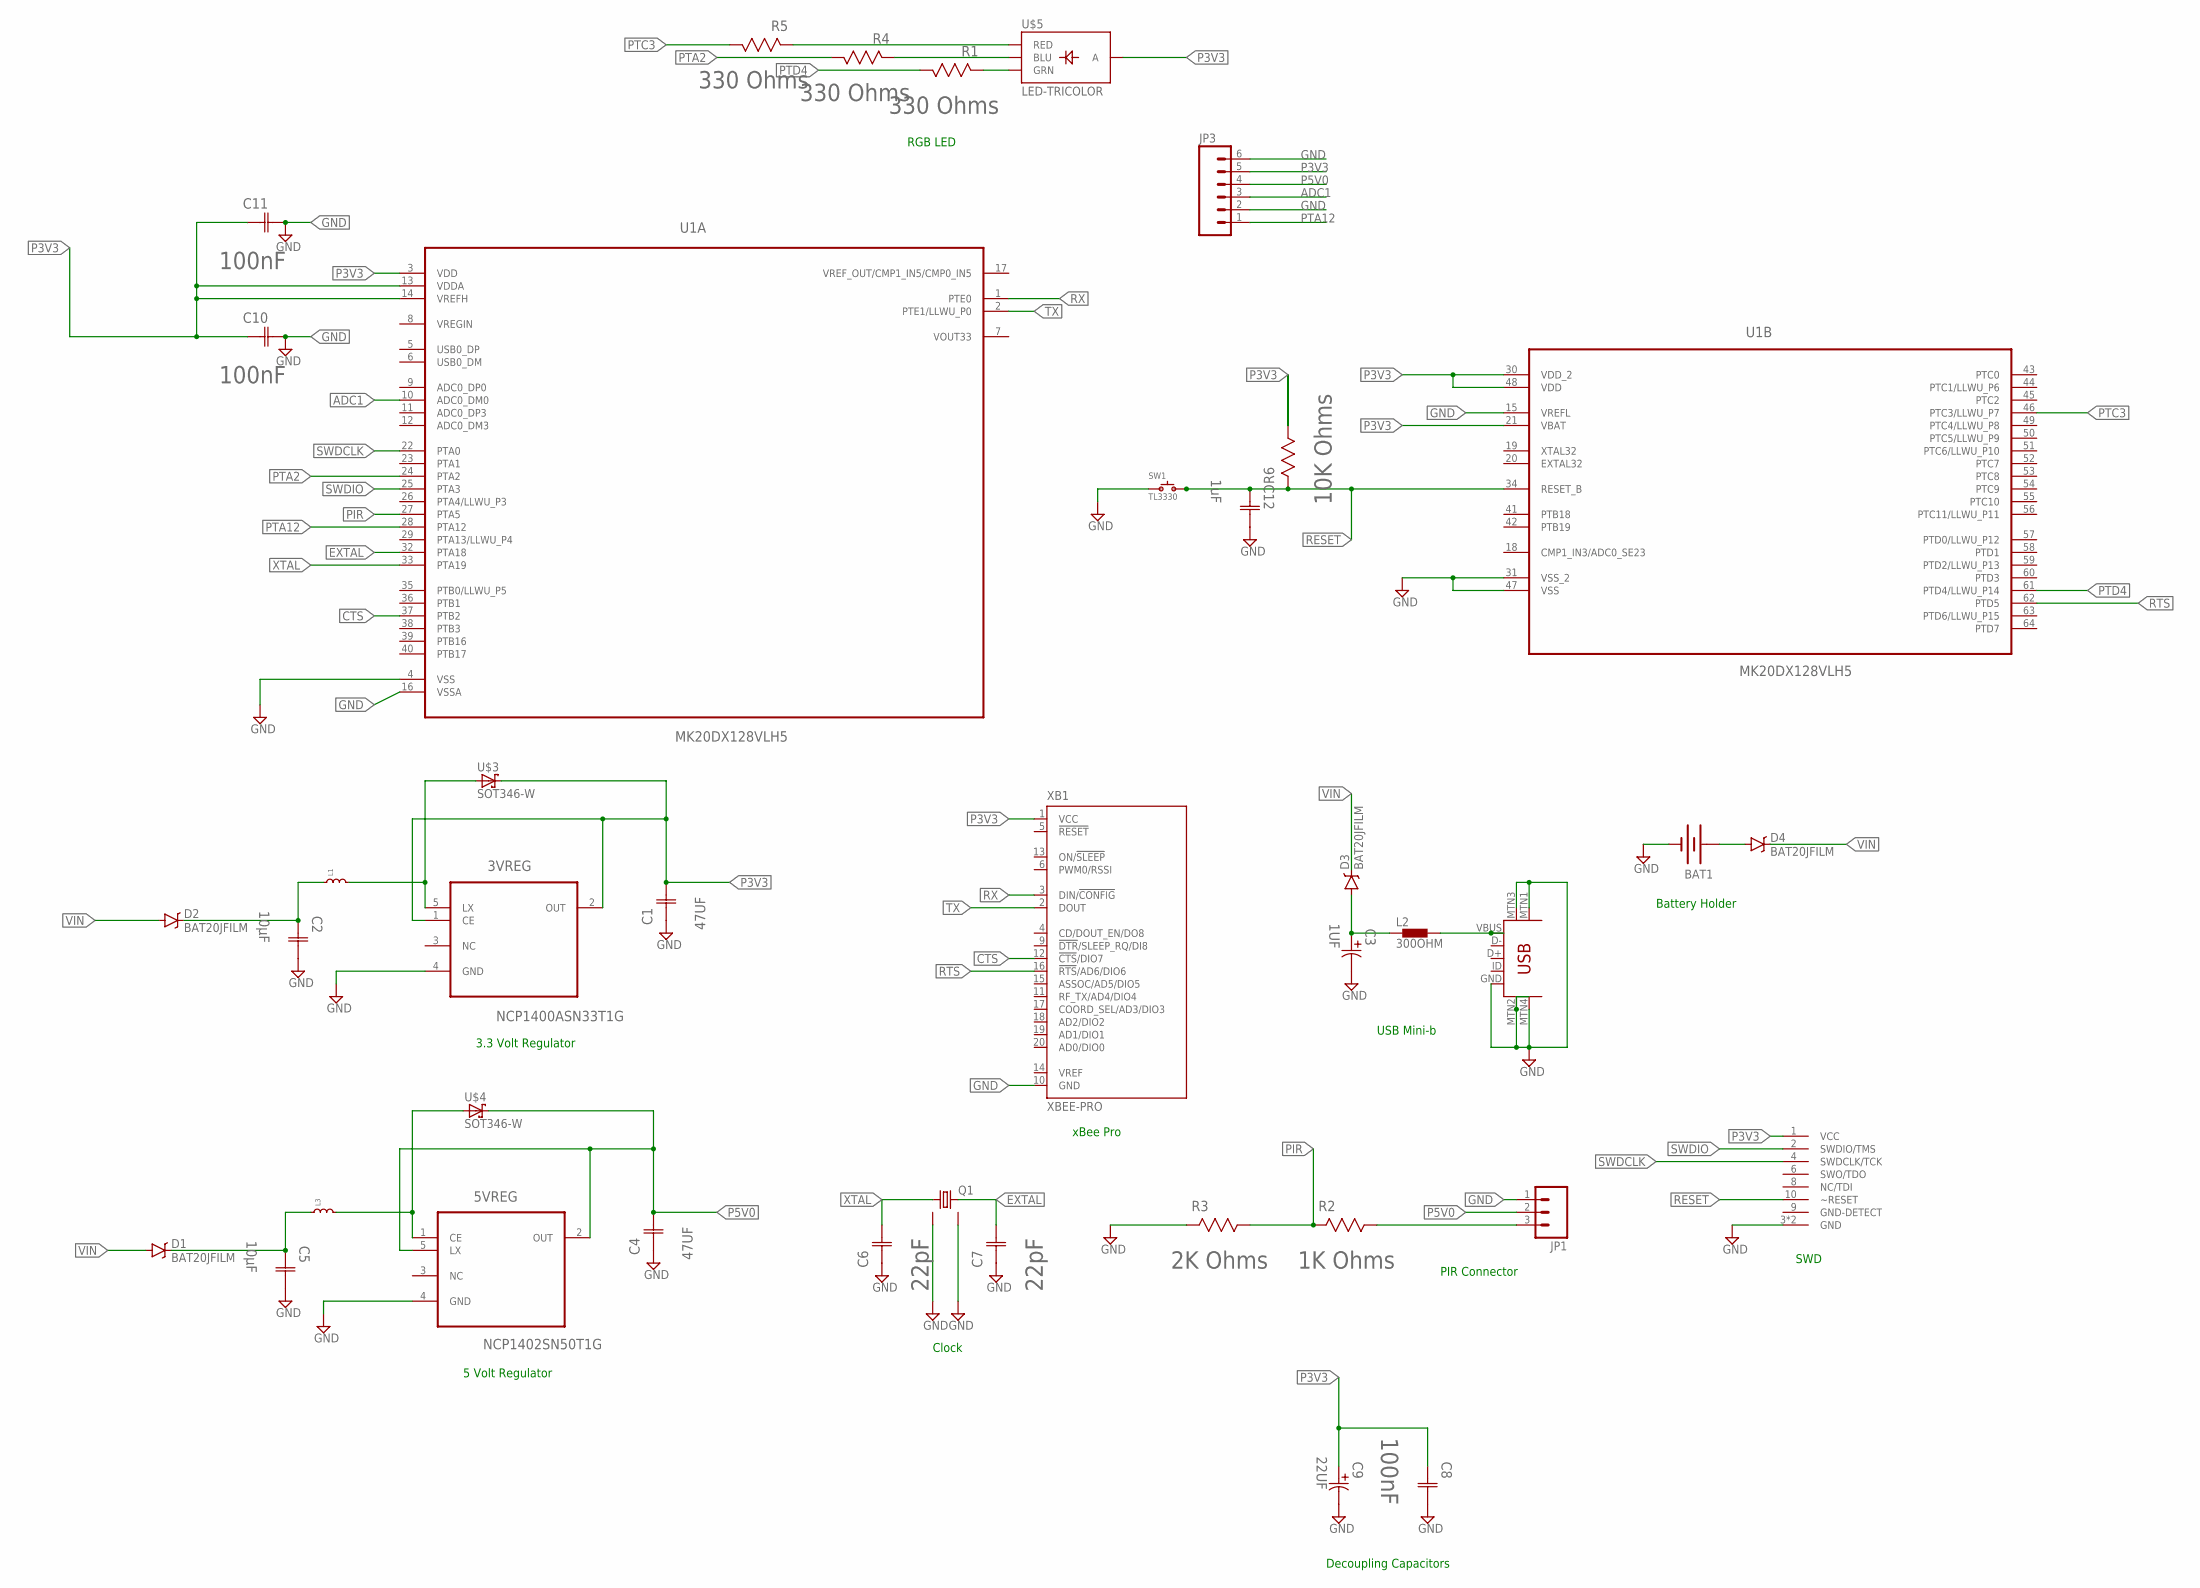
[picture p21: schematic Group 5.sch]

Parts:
3VREG: NCP1400ASN33T1G; SOT95P275X110-5N
5VREG: NCP1402SN50T1G; SOT95P275X110-5N
BAT1: BATTERY20PTH; BATTCOM_20MM_PTH
C1, C4: 47UF; CAPCP6032X280N
C2, C5: 10µF; CAPCP6032X280N
C3: 1UF; CAPAE430X610N
C6, C7: 22pF; CAPC1608X85N
C8, C10, C11: 100nF; CAPC2013X95N
C9: 22UF; CAPAE430X610N
C12: 1uF; CAPC1608X94N
D1, D2, D3, D4: BAT20JFILM; SOD-323
JP1: M03PTH; 1X03
JP3: M06LONGPADS; 1X06_LONGPADS
L1, L3: INDUCTOR-SDR0403; SDR0403
L2: 300OHM; 0402
Q1: CRYSTALCTS406; CTS406
R1, R4, R5: 330 Ohms; RESC2013X65N
R2: 1K Ohms; RESC3216X71N
R3: 2K Ohms; RESC3216X71N
R6: 10K Ohms; RESC1608X60N
SW1: TL3330
U1: MK20DX128VLH5; QFP50P1200X1200X160-64N
U$1: 2X5_0.05"_CORTEX_DEBUGTH_NOKEY_UNSHROUDED; 2X5_0.05"_TH_NS
U$2: USB-MINIB-5PIN; USB-MINIB
U$3, U$4: SOT346-W
U$5: LED-TRICOLOR; LED-TRICOLOR-SMD
XB1: XBEE-PRO

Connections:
ADC1: JP3.3, U1.10 (ADC0_DM0)
CTS: U1.37 (PTB2), XB1.12 (!CTS!/DIO7)
EXTAL: C7.2 (C2), Q1.3 (2), U1.32 (PTA18)
GND: 3VREG.4 (GND), 5VREG.4 (GND), BAT1.2 (-), C1.1 (C1), C2.2 (C2), C3.2, C4.1 (C1), C5.2 (C2), C6.1 (C1), C7.1 (C1), C8.2 (C2), C9.2, C10.2 (C2), C11.2 (C2), C12.2 (C2), JP1.1, JP3.2, JP3.6, Q1.2 (GND1), Q1.4 (GND2), R3.2 (R2), SW1.1, U1.4 (VSS), U1.15 (VREFL), U1.16 (VSSA), U1.31 (VSS_2), U1.47 (VSS), U$1.3 (GND), U$1.5 (GND), U$2.GND, U$2.MTN1 (MTN2), U$2.MTN2 (MTN3), U$2.MTN3 (MTN1), U$2.MTN4, XB1.10 (GND)
unnamed: 3VREG.5 (LX), L1.2, U$3.1 (A)
unnamed: L2.2, U$2.VBUS
unnamed: 5VREG.1 (CE), L3.2, U$4.1 (A)
unnamed: JP1.3, R2.1 (R1)
unnamed: R1.2 (R2), U$5.G (GRN)
unnamed: R4.2 (R2), U$5.B (BLU)
unnamed: R5.2 (R2), U$5.R (RED)
unnamed: BAT1.1 (+), D4.A
P3V3: 3VREG.1 (CE), 3VREG.2 (OUT), C1.2 (C2), C8.1 (C1), C9.1, C10.1 (C1), C11.1 (C1), JP3.5, R6.1 (R1), U1.3 (VDD), U1.13 (VDDA), U1.14 (VREFH), U1.21 (VBAT), U1.30 (VDD_2), U1.48 (VDD), U$1.1 (VCC), U$3.3 (C), U$5.A, XB1.1 (VCC)
P5V0: 5VREG.2 (OUT), 5VREG.5 (LX), C4.2 (C2), JP1.2, JP3.4, U$4.3 (C)
PIR: R2.2 (R2), R3.1 (R1), U1.27 (PTA5)
PTA2: R4.1 (R1), U1.24 (PTA2)
PTA12: JP3.1, U1.28 (PTA12)
PTC3: R5.1 (R1), U1.46 (PTC3/LLWU_P7)
PTD4: R1.1 (R1), U1.61 (PTD4/LLWU_P14)
RE: C2.1 (C1), D2.C, L1.1
RE3: C5.1 (C1), D1.C, L3.1
RESET: C12.1 (C1), R6.2 (R2), SW1.2, U1.34 (RESET_B), U$1.10 (~RESET)
RTS: U1.62 (PTD5), XB1.16 (!RTS!/AD6/DIO6)
RX: U1.1 (PTE0), XB1.3 (DIN/!CONFIG)
SWDCLK: U1.22 (PTA0), U$1.4 (SWDCLK/TCK)
SWDIO: U1.25 (PTA3), U$1.2 (SWDIO/TMS)
TX: U1.2 (PTE1/LLWU_P0), XB1.2 (DOUT)
VIN: D1.A, D2.A, D3.C, D4.C
VIN3: C3.1, D3.A, L2.1
XTAL: C6.2 (C2), Q1.1, U1.33 (PTA19)

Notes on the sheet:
Clock
5 Volt Regulator
3.3 Volt Regulator
USB Mini-b
PIR Connector
xBee Pro
SWD
Battery Holder
Decoupling Capacitors
RGB LED

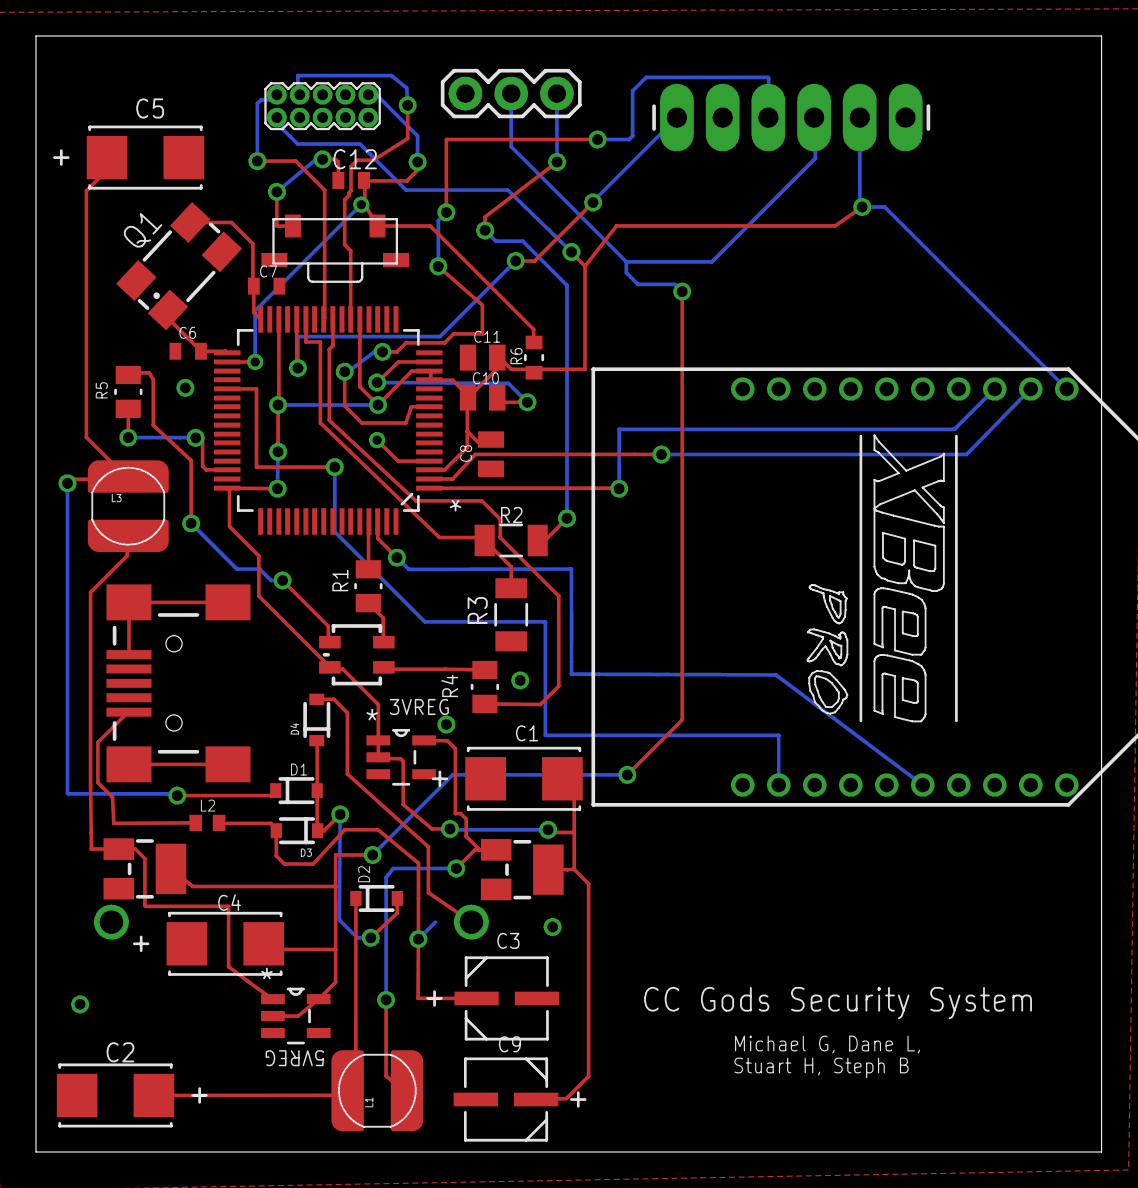
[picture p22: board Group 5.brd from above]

Board: 2 copper layers, 59.2 x 62.0 mm, 39 parts (1 on the bottom side), 30 nets.

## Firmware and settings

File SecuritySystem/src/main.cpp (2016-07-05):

#include "camera.h"
#include <opencv2/opencv.hpp>
#include <opencv2/core/core.hpp>
#include <opencv2/highgui/highgui.hpp>
#include "opencv2/imgproc/imgproc.hpp"
#include <iostream>
#include <cstdio>
#include <sys/time.h>
#include <fcntl.h>
#include <termios.h>
#include <stdio.h>
#include <string.h>
#include <unistd.h>
#include <errno.h>
#include <stdint.h>
#include <stdlib.h>
#include <arpa/inet.h>
#include <stdlib.h>
#include <errno.h>
#include <sys/types.h>
#include <sys/socket.h>
#include <netinet/in.h>
#include <arpa/inet.h>
#include <netdb.h>
#include <assert.h>
#include <sys/select.h>


// sphinxbase includes
#include <sphinxbase/err.h>
#include <sphinxbase/ad.h>

// pocketsphinx include
#include <pocketsphinx.h>

using namespace cv;

static ps_decoder_t *ps;
static cmd_ln_t *config;

Mat emailPhoto1, emailPhoto2, emailPhoto3;
int motionLoopCounter = 0;
int largestMotion = 20;
int isArmed = 1;
int isVoiceControlled = 0;
static int serial_port = 0;

// Capture size
#define WIDTH 512
#define HEIGHT 512
/* THE FOLLOWING FUNCTION CHECKS FOR MOTION BY COMPARING THREE FRAMES
AND GENERATING A BINARY IMAGE WHERE WHITE PIXELS REPRESENT PIXELS THAT
SHOWED CHANGE FROM FRAME-TO-FRAME AND BLACK PIXELS WERE THOSE THAT REMAINED
UNCHANGED BETWEEN FRAMES. WHITE PIXELS ARE COUNTED TO DETERMINE WHETHER
MOVEMENT OCCURRED. RETURNS 1 IF PIXEL COUNT IS > 0. */
static bool init_serial(char *port)
{
	printf("Opening serial port %s\n", port);

	// Open the serial port for reading and writing
	// Using non-blocking so 'read' won't block the code
	serial_port = open(port, O_RDWR, O_NONBLOCK);

	// If the serial port doesn't open return an error
	if (serial_port == -1) {
		fprintf(stderr, "Failed to open serial port:\n%s\n", strerror(errno));
		return false;
	}

	// Configure the serial port
	termios tio; // termios is a struct defined in termios.h
	memset(&tio, 0, sizeof(termios)); // Zero out the tio structure
	tio.c_cflag = CS8; // Select 8 data bits
	tio.c_cc[VMIN] = 0; // Demand at least 1 char from every call to read(), i.e. block execution until a char is received
	cfsetospeed(&tio, B9600); // baud rate for output
	cfsetispeed(&tio, B9600); // baud rate for input
	tcsetattr(serial_port, TCSANOW, &tio); // Apply these settings

	// Done
	return true;
}

// THIS FUNCTION SETS THE GLOBAL LARGEST MOTION VARIABLE TO A DESIRED VALUE
void setLargestMotion(int motionThreshold){
	largestMotion = motionThreshold;
}

// THIS FUNCTION INCREMENTS THE GLOBAL MOTION LOOP COUNTER VARIABLE
void increaseMotionCounter(){
	++motionLoopCounter;
}

// THIS FUNCTION RESETS THE GLOBAL MOTION LOOP COUNTER VARIABLE
void resetMotionCounter(){
	motionLoopCounter = 0;
}

// THIS FUNCTION RETURNS THE CURRENT VALUE OF THE GLOBAL MOTION LOOP COUNTER VARIABLE
int getMotionCounterValue(){
	return motionLoopCounter;
}

// THIS FUNCTION SAVES PHOTOS FOR EMAILING USING THE GLOBAL PHOTO VARIABLES
void saveEmailPhotos(){
	imwrite("/home/pi/PiCapture/src/frame1.jpg", emailPhoto1);
	imwrite("/home/pi/PiCapture/src/frame2.jpg", emailPhoto2);
	imwrite("/home/pi/PiCapture/src/frame3.jpg", emailPhoto3);
}

// THIS FUNCTION EMAILS THE PHOTOS
void emailPhotos(){
	printf("Email Photo Sequence Begins\n");
	system("python emailSystem.py");
}

// THIS FUNCTION PROVIDES A MEANS FOR MAKING THE CODE WAIT TEMPORARILY
void delay(int iterations){
	for (int i = 0; i < iterations; ++i);
}

// THE FOLLOWING FUNCTION CHECKS FOR MOTION AND RETURNS TRUE IF IT IS DETECTED
bool checkForMotion(Mat previousFrame1, Mat previousFrame2, Mat currentFrame){
	Mat difference1, difference2, result;
	int pixelcount = 0;
	int min_x = 0;
	int max_x = 0;
	int min_y = 0;
	int max_y = 0;

	// calculate difference per element in the image matrices
	absdiff(previousFrame1, currentFrame, difference1);
	absdiff(previousFrame2, currentFrame, difference2);

	// bitwise logical and operation, eliminates noise in result
	// should minimise false readings
	bitwise_and(difference1, difference2, result);

	// convert to greyscale, reduces noise a little more
	cvtColor(result, result, CV_BGR2GRAY);

	// threshold the difference image, eliminates last of noise
	threshold(result, result, 25, 255, CV_THRESH_BINARY);

	// look at each pixel in the image
	for (int x = 0; x < WIDTH; ++x){
		for (int y = 0; y < HEIGHT; ++y){
			// check if the pixel is white
			if(result.at<uchar>(Point(x, y)) == 255){
				// check whether the pixel is at a min/max position
				if (pixelcount == 0){
					min_x = x;
					max_x = x;
					min_y = y;
					max_y = y;
				} else {
					if (x < min_x) {
						min_x = x;
					} else if (x > max_x){
						max_x = x;
					}

					if (y < min_y){
						min_y = y;
					} else if (y > max_y){
						max_y = y;
					}
				}
				// count the white pixels
				++pixelcount;
			}
		}
	}
	printf("%i\n",pixelcount);

	// Expand the min and max x points for a bounding rectangle that won't
	// cut off any details of the thing moving
	if (min_x > 10) {
		min_x -= 10;
	} else if (max_x < WIDTH - 10){
		max_x += 10;
	}

	// Expand the min and max y points for a bounding rectangle that won't
	// cut off any details of the thing moving
	if (min_y > 10) {
		min_y -= 10;
	} else if (max_y < HEIGHT - 10){
		max_y += 10;
	}

	// draw a bounding rectangle around the movement in each frame
	rectangle(currentFrame, Point(min_x, min_y), Point(max_x, max_y), Scalar(255), 5);
	rectangle(previousFrame1, Point(min_x, min_y), Point(max_x, max_y), Scalar(255), 5);
	rectangle(previousFrame2, Point(min_x, min_y), Point(max_x, max_y), Scalar(255), 5);

	// save for debugging and emailing
	if (pixelcount > largestMotion){
		emailPhoto1 = previousFrame1.clone();
		emailPhoto2 = previousFrame2.clone();
		emailPhoto3 = currentFrame.clone();
		largestMotion = pixelcount;
	}

	if (pixelcount > 20){
		return true;
	} else {
		return false;
	}
}

/* THE FOLLOWING FUNCTION CAPTURES AN IMAGE FOR THE STREAM UNLESS THE
IMAGE CAPTURE FAILS */
int createStreamImage(Mat originalImage){
	// Save the image yay
	imwrite("/home/pi/PiCapture/src/t.jpg", originalImage);
	char tempImage[] = "t.jpg";
	char currentImage[] = "c.jpg";
	int result;
	result = rename ( tempImage, currentImage );
	return 1;
}

int main(int argc, char *argv[])
{
	// Initialise the serial port
	if (!init_serial(argv[1])) {
		return 1;
	}

	int pirBytesRead;
	char pirChar;

	// Open a socket for receiving
	// This is initialization
	int udpSocket, numSocketBytes;
	struct addrinfo hints, *res;
	char buf[2];
	struct sockaddr_storage theirAddress;
	socklen_t addressLength;

	// Load up address structs
	memset(&hints, 0, sizeof hints);
	hints.ai_family = AF_INET;
	hints.ai_socktype = SOCK_DGRAM;
	hints.ai_flags = AI_PASSIVE;

	// Get address info
	getaddrinfo(NULL, "3501", &hints, &res);

	// Create a socket and set it to non-block
	udpSocket = socket(PF_INET, SOCK_DGRAM, 0);
	fcntl(udpSocket, F_SETFL, O_NONBLOCK);

	// Bind socket to the required port
	bind(udpSocket, res->ai_addr, res->ai_addrlen);

	// Free the address info
	freeaddrinfo(res);

	// Get address length
	addressLength = sizeof theirAddress;

	// THIS IS THE VOICE CONTROL SET UP //
	config = cmd_ln_init(NULL, ps_args(), TRUE, "-lm", "/home/pi/PiCapture/src/commands.lm", "-dict", "/home/pi/PiCapture/src/commands.dic", NULL);

	// Configure PocketSphinx
	ps_default_search_args(config);
	ps = ps_init(config);

	// Start listening to the microphone
	ad_rec_t *ad;
	int16 adbuf[2048];
	uint8 utt_started, in_speech;
	int32 k;
	char const *hyp;
	char message[256];

	// Check that the device has been opened properly
	if ((ad = ad_open_dev(cmd_ln_str_r(config, "-adcdev"),
		(int) cmd_ln_float32_r(config,
			"-samprate"))) == NULL){
				// Throw fatal error if it hasn't
		E_FATAL("Failed to open audio device\n");
		}

	// Check that recording is working
if (ad_start_rec(ad) < 0) {
				// Throw fatal error if it isn't
	E_FATAL("Failed to start recording\n");
}

	// Check that utterance has been started
if (ps_start_utt(ps) < 0){
				// Throw a fatal error if it hasn't
	E_FATAL("Failed to start utterance\n");
}

	// utterance hasn't started yet
utt_started = FALSE;

	// Open the camera at 30fps, one level of downsampling, and BGR conversion
CCamera* cam = StartCamera(WIDTH, HEIGHT, 30, 1, true);
	// some matrices to save our images into
Mat originalImage, previousFrame1, previousFrame2, currentFrame;

	// Let the user know we're ready to go
system("espeak -v en/en-sc -s 130 \"Welcome, we are ready to go!\"");

for (;;) {

			// Capture an image for the stream
	originalImage = cam->Capture(0);
	createStreamImage(originalImage);

			// If no image is captured, continue anyway but print an error
	if (!originalImage.data) {
		printf("Stream image capture failed\n");
		continue;
	}

			// Check the socket for data
	if ((numSocketBytes = recvfrom(udpSocket, buf, 4 , 0,
		(struct sockaddr *)&theirAddress, &addressLength)) > 0) {
		printf("Packet is %d bytes long\n", numSocketBytes);
	printf("Packet contains %s\n", buf);
	sscanf(buf, "%i,%i", &isArmed, &isVoiceControlled);
	}
			// Read from the serial port to see if PIR sensor is detecting motion
	pirBytesRead = read(serial_port, &pirChar, 1);
			// PIR sends 'h' when it detects motion; run motion detection when that happens
if (isVoiceControlled == 0 && isArmed == 1 && pirChar == 'h'){
	printf("Motion from PIR Detected\n");
				// If motion has been detected by the PIR, capture three frames for motion detection
	previousFrame1 = cam->Capture(0);
	delay(800);
	previousFrame2 = cam->Capture(0);
	delay(1500);
	currentFrame = cam->Capture(0);

					// Call motion detection function to check for motion
	bool motion = checkForMotion(previousFrame1, previousFrame2, currentFrame);
	if (motion) {
		printf("Motion Detected from Camera\n");
					// Increase motion loop counter
		increaseMotionCounter();

					// Only email images every 5 captures
					// Images sent are the ones with the largest motion detection
		if (getMotionCounterValue() == 2){
			pid_t sendEmailFork = fork();
			if (sendEmailFork == 0){
							// Save images for the child program to use
				saveEmailPhotos();
				emailPhotos();
				return 1;
			}
		} else if (getMotionCounterValue() > 2) {
						// Delay slightly before resetting the largest motion
			resetMotionCounter();
			setLargestMotion(20);
		}
	} else {
		printf("No Motion Detected from Camera\n");
	}

				// Allow openCV to process GUI events
	waitKey(10);
	}

if (isVoiceControlled == 1){
			// throw fatal error if audio breaks
	if ((k = ad_read(ad, adbuf, 2048)) < 0){
		E_FATAL("Failed to read audio\n");
	}

	ps_process_raw(ps, adbuf, k, FALSE, FALSE);
	in_speech = ps_get_in_speech(ps);

			// If the user is speaking, start the utterance
	if (in_speech && !utt_started) {
		utt_started = TRUE;
	}

			// If the user has stopped speaking after the utterance has started
	if (!in_speech && utt_started) {
					// End the utterance and process the speech contents
		ps_end_utt(ps);

					// this function gets the string that was heard
		hyp = ps_get_hyp(ps, NULL);
					// If there is a message, do things with it
		if (hyp) {
						// Get the contents of the message and put it in a string
			sscanf(hyp, "%s", message);
						printf("%s\n", message); // just for debugging

						// compare the message with commands
						if (strcmp(message, "ARM") == 0){
							isArmed = 1;
							printf("User said - ARM");
						} else if (strcmp(message, "DISARM") == 0){
							isArmed = 0;
							printf("User said DISARM");
						} else if (strcmp(message, "TAKEPHOTO") == 0){
							previousFrame1 = cam->Capture(0);
							for (int i = 0; i < 800; ++i);
								previousFrame2 = cam->Capture(0);
							for (int i = 0; i < 1500; ++i);
								currentFrame = cam->Capture(0);
							int motion = checkForMotion(previousFrame1, previousFrame2, currentFrame);
							if (motion == 1) {
								pid_t sendEmailFork = fork();
								if (sendEmailFork == 0){
											// Save images for the child program to use
									saveEmailPhotos();
									emailPhotos();
									return 1;
								}
							}
						} else if (strcmp(message, "GOODBYE") == 0){
							isVoiceControlled = 0;
						} else {
							system("espeak -v en/en-sc -s 130 \"Sorry, could you please repeat that?\"");
						}
					}
					memset(message, 0, 256);

						// If the utterance didn't start properly throw a fatal error
					if (ps_start_utt(ps) < 0){
						E_FATAL("Failed to start utterance\n");
						utt_started = FALSE;
						//printf("READY....\n");
					}
				}
}
}


		close(udpSocket);
		StopCamera();
		ad_close(ad);
		ps_free(ps);
		cmd_ln_free_r(config);
	}

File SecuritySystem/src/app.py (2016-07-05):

#!/usr/bin/env python
from flask import Flask, render_template, make_response, Response, request, redirect, send_from_directory
from camera import Camera
import time
import shutil
import socket
from functools import wraps, update_wrapper
from datetime import datetime
app = Flask(__name__)

cam = Camera()

i=0
isArm = 1;
isVoiceControl = 0;


def check_auth(username, password):
    return username == 'Group5' and password == 'HD'

def authenticate():
    return Response(
    'Could not verify your access level for that URL.\n'
    'You have to login with proper credentials', 401,
    {'WWW-Authenticate': 'Basic realm="Login Required"'})

def requires_auth(f):
    @wraps(f)
    def decorated(*args, **kwargs):
        auth = request.authorization
        if not auth or not check_auth(auth.username, auth.password):
            return authenticate()
        return f(*args, **kwargs)
    return decorated

def nocache(view):
    @wraps(view)
    def no_cache(*args, **kwargs):
        response = make_response(view(*args, **kwargs))
        response.headers['Last-Modified'] = datetime.now()
        response.headers['Cache-Control'] = 'no-store, no-cache, must-revalidate, post-check=0, pre-check=0, max-age=0'
        response.headers['Pragma'] = 'no-cache'
        response.headers['Expires'] = '-1'
        return response
        
    return update_wrapper(no_cache, view)

@app.route('/')
@requires_auth
def index():
    return render_template('index.html')

def gen(camera):
    while True:
        frame = camera.get_frame()
        yield (b'--frame\r\n'
               b'Content-Type: image/jpeg\r\n\r\n' + frame + b'\r\n')

@app.route('/image.jpeg')
def image():
    return Response(cam.get_frame(), mimetype='image/jpeg')

@app.route('/emailSetup')
def my_form():
    return render_template('emailSetup.html')

@app.route('/emailSetup', methods=['POST'])
def my_form_post():
    text = request.form['text']
    file = open('email.txt','w')
    file.write(text)
    file.close()
    return render_template('emailSetup.html')


@app.route('/viewSnapShots')
@nocache
def viewSnapShots():
    return render_template('viewSnapShots.html')

@app.route('/video_feed')
def video_feed():
    return Response(gen(Camera()),
                    mimetype='multipart/x-m, mixed-replace; boundary=frame')


@app.route('/images/<path:path>')
@nocache
def static_file(path):
    return send_from_directory('images',path)


@app.route('/screenshot', methods = ['GET','POST'])
def doScreenshot():
    global i
    i += 1
    if (i==13):
        i=1

    buf = 'images/' + str(i) + '.png'
    shutil.copy2('c.jpg',buf)
    return render_template('index.html')

@app.route('/email', methods = ['GET','POST'])
def doEmail():
    execfile('emailWeb.py')
    return render_template('index.html')

@app.route('/arm', methods = ['GET','POST'])
def doArm():
    global isArm
    isArm = 1
    sendMessage()
    return render_template('index.html')

@app.route('/disarm', methods = ['GET','POST'])
def doDisarm():
    global isArm
    isArm = 0
    sendMessage()
    return render_template('index.html')

@app.route('/voiceoff', methods = ['GET','POST'])
def doDisableVoice():
    global isVoiceControl
    isVoiceControl = 0
    sendMessage()
    return render_template('index.html')

@app.route('/voiceon', methods = ['GET','POST'])
def doEnableVoice():
    global isVoiceControl
    isVoiceControl = 1
    sendMessage()
    return render_template('index.html')

def sendMessage():
    global isArm
    global isVoiceControl

    UDP_IP = ''
    UDP_PORT = 3501
    MESSAGE = str(isArm) + ',' + str(isVoiceControl);

    sendSocket = socket.socket(socket.AF_INET, socket.SOCK_DGRAM)
    sendSocket.connect((UDP_IP, UDP_PORT));
    sendSocket.sendall(MESSAGE)
    sendSocket.close()
    return 1




if __name__ == '__main__':
    app.run(host='0.0.0.0', debug=True, threaded=True)

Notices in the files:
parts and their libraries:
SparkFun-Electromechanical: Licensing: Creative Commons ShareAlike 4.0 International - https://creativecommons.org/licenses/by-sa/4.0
